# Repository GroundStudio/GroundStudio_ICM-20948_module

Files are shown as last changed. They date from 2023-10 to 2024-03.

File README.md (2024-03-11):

GroundStudio ICM-20948 module
====================================
ICM-20948 module REV0 0 1

Get it from [ardushop.ro](https://ardushop.ro/ro/home/2659-groundstudio-icm-20948.html)

Explore all the GroundStudio products at [GroundStudio.ro](https://groundstudio.ro/)

Description
-------------------
Low power, 9-axis MotionTracking module based on ICM-20948 chip.

Contents
-------------------

* [/Documentation](https://github.com/GroundStudio/GroundStudio_ICM-20948_module/tree/main/Documentation) -- Contains documentation written during creation of this repository, with readme.md index of its own!
* [/Firmware](https://github.com/GroundStudio/GroundStudio_ICM-20948_module/tree/main/Firmware) -- Firmware (bootloaders, etc)
* [/Hardware](https://github.com/GroundStudio/GroundStudio_ICM-20948_module/tree/main/Hardware) -- Schematics, layout.
* [/Libraries](https://github.com/GroundStudio/GroundStudio_ICM-20948_module/tree/main/Libraries) -- Arduino/CircuitPython libraries. 
* [/Tools](https://github.com/GroundStudio/GroundStudio_ICM-20948_module/tree/main) -- Tools needed for compiling, uploading bootloader, etc.

Versions
-------------------
*(Not all tags shown)*
* [V0.0.1] Initial version

License
-------------------

This is released under the [Attribution-ShareAlike 4.0 International (CC BY-SA 4.0)](https://creativecommons.org/licenses/by-sa/4.0/) license. 
**You are welcome to use this for commercial purposes.**

Please consider contributing back to this project or others to help the open-source hardware community continue to thrive and grow! 

Certifications:

[Open Source Hardware Association](https://certification.oshwa.org/ro000015.html)   
   
certification-mark-RO000015-wide (https://certification.oshwa.org/ro000015.html)

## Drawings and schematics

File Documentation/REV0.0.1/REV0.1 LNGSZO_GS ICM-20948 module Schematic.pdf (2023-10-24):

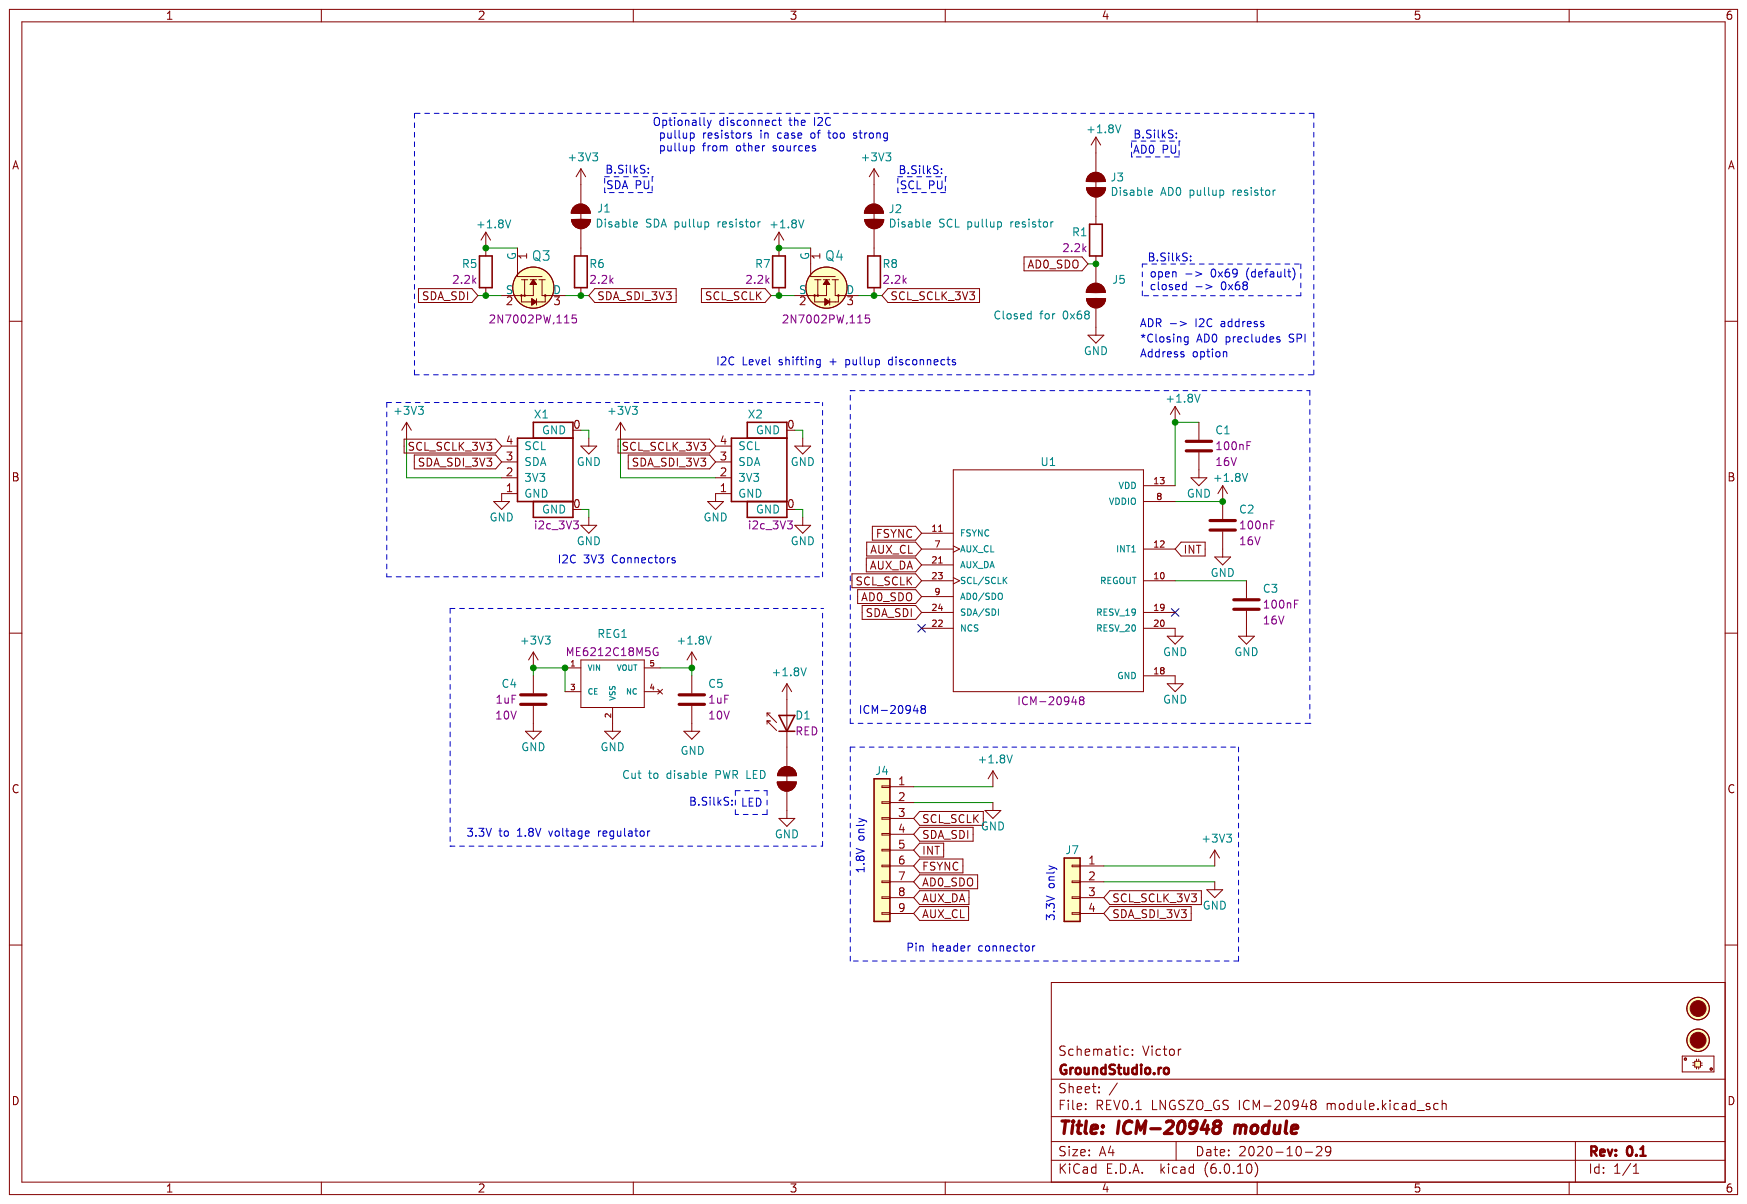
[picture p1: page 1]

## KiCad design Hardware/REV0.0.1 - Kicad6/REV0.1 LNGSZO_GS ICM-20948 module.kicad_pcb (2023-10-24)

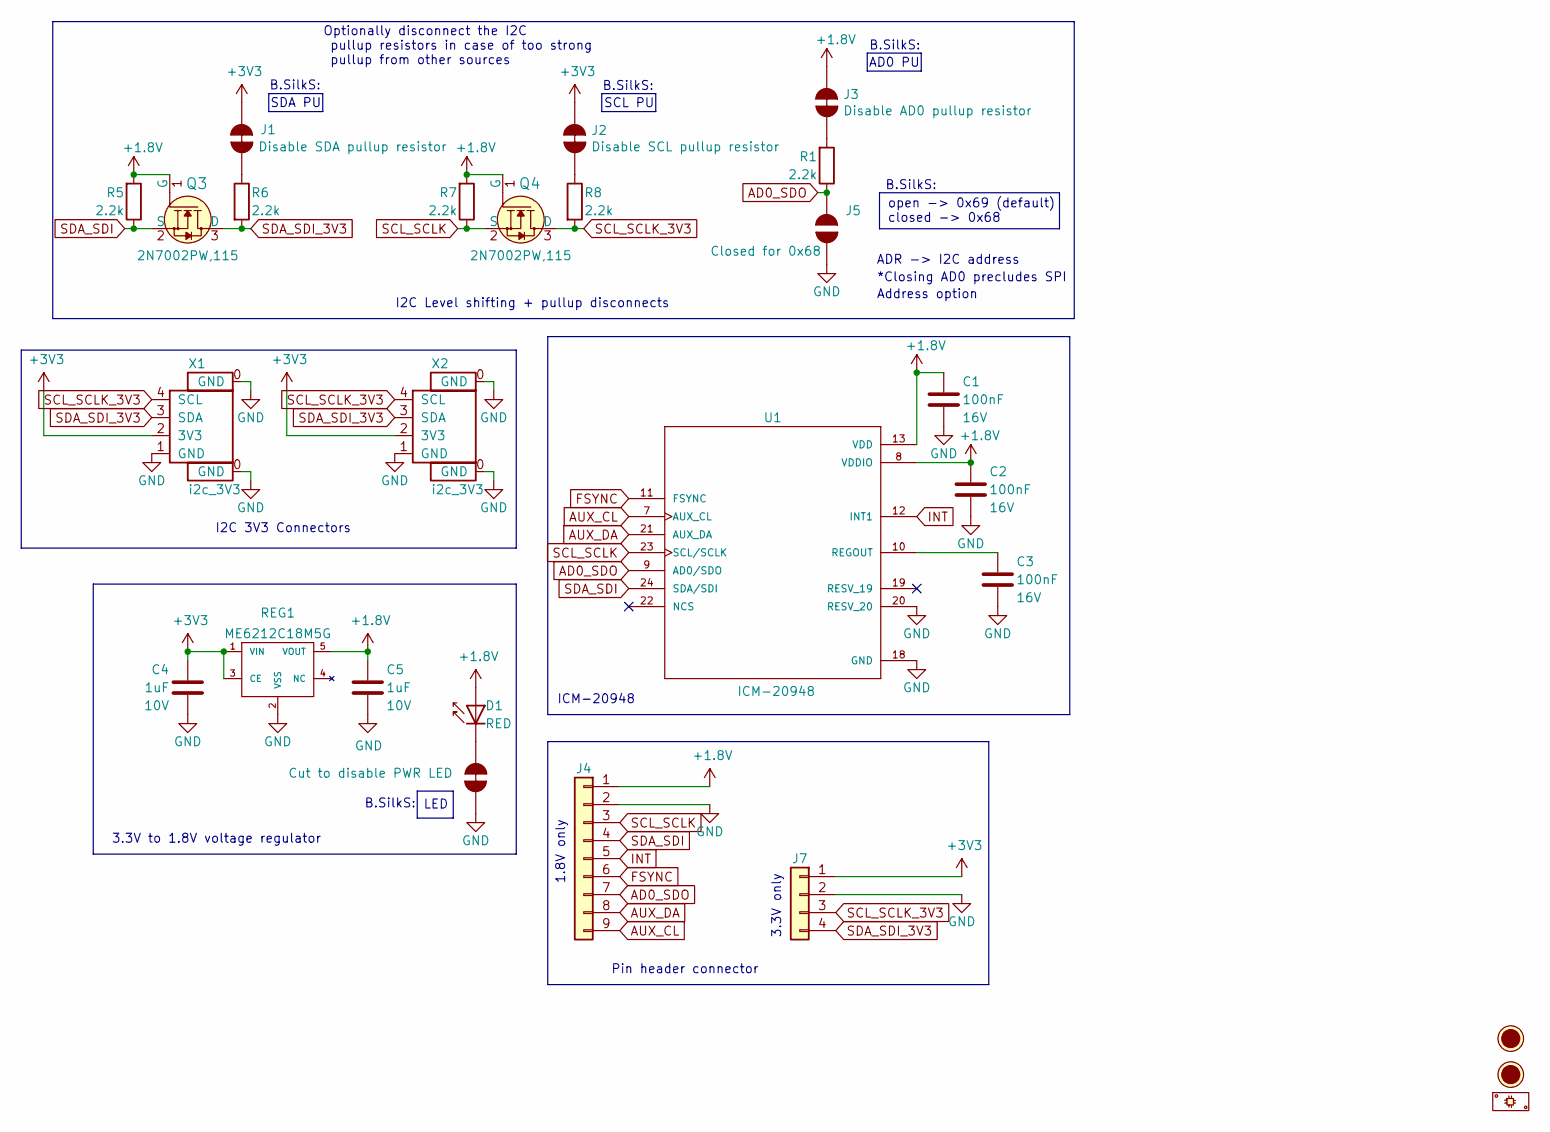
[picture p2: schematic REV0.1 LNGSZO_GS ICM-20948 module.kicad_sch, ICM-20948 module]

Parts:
C1, C2, C3: C_0402_100nF_16V; C_0402; Rated voltage 16V; MPN 0402B104K160CT; LCSC C83056
C4, C5: C_0402_1uF_10V; C_0402; Rated voltage 10V; MPN FS15B105K100PKG; LCSC C525324
D1: LED_0402_RED; LED_0402; MPN TZ-P2-0402RTIA1-0.45T; LCSC C779449
FID1, FID2: Fiducial; Fiducial_0.75mm_Mask1.5mm
J1: Disable SDA pullup resistor; SolderJumper_NC
J2: Disable SCL pullup resistor; SolderJumper_NC
J3: Disable AD0 pullup resistor; SolderJumper_NC
J4: PinHeader_1x09_P2.54_V_M; PinHeader_1x09_P2.54mm_Vertical_Male; MPN A2541WV-9P; LCSC C225484
J5: Closed for 0x68; SolderJumper_NO
J6: Cut to disable PWR LED; SolderJumper_NC
J7: PinHeader_1x04_P2.54_V_M; PinHeader_1x04_P2.54mm_Vertical_Male; MPN MTP125-1104S1; LCSC C358686
P1: PCB; MPN LNGSZO_GS_PCB
Q3, Q4: SOT-323 2N7002PW; SOT-323_SC-70; MPN 2N7002PW,115; LCSC C255579
R1, R5, R6, R7, R8: R_0402_2.2k; R_0402; MPN RC-02W2201FT; LCSC C258093
REG1: SOT-23-5_ME6212C18M5G; SOT-23-5; MPN ME6212C18M5G; LCSC C236669
U1: QFN-24_ICM-20948; QFN-24-0EP_3x3mm_P0.4mm_NO-EP; MPN ICM-20948; Mouser 410-ICM-20948
X1, X2: SH_1x04_P1.0_H; SH__1x04_P1.00mm_Horizontal; MPN C145956; LCSC C145956

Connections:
+1.8V: C1.1, C2.1, C5.1, D1.2 (A), J3.1, J4.1, Q3.1 (G), Q4.1 (G), R5.2, R7.2, REG1.5 (VOUT), U1.8 (VDDIO), U1.13 (VDD)
+3V3: C4.2, J1.1, J2.1, J7.1, REG1.1 (VIN), REG1.3 (CE), X1.2 (3V3), X2.2 (3V3)
AD0_SDO: J4.7, J5.1, R1.1, U1.9 (AD0/SDO)
AUX_CL: J4.9, U1.7 (AUX_CL)
AUX_DA: J4.8, U1.21 (AUX_DA)
FSYNC: J4.6, U1.11 (FSYNC)
GND: C1.2, C2.2, C3.2, C4.1, C5.2, J4.2, J5.2, J6.1, J7.2, REG1.2 (VSS), U1.18 (GND), U1.20 (RESV_20), X1.0 (GND), X1.1 (GND), X2.0 (GND), X2.1 (GND)
INT: J4.5, U1.12 (INT1)
unnamed: C3.1, U1.10 (REGOUT)
unnamed: D1.1 (K), J6.2
unnamed: J1.2, R6.1
unnamed: J2.2, R8.1
unnamed: J3.2, R1.2
SCL_SCLK: J4.3, Q4.2 (S), R7.1, U1.23 (SCL/SCLK)
SCL_SCLK_3V3: J7.3, Q4.3 (D), R8.2, X1.4 (SCL), X2.4 (SCL)
SDA_SDI: J4.4, Q3.2 (S), R5.1, U1.24 (SDA/SDI)
SDA_SDI_3V3: J7.4, Q3.3 (D), R6.2, X1.3 (SDA), X2.3 (SDA)

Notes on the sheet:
LED
I2C 3V3 Connectors
3.3V only
B.SilkS:
Address option
AD0 PU
SDA PU
SCL PU
open -> 0x69 (default) closed -> 0x68
Optionally disconnect the I2C pullup resistors in case of too strong pullup from other sources
3.3V to 1.8V voltage regulator
*Closing AD0 precludes SPI
ADR -> I2C address
ICM-20948
I2C Level shifting + pullup disconnects
Pin header connector
1.8V only

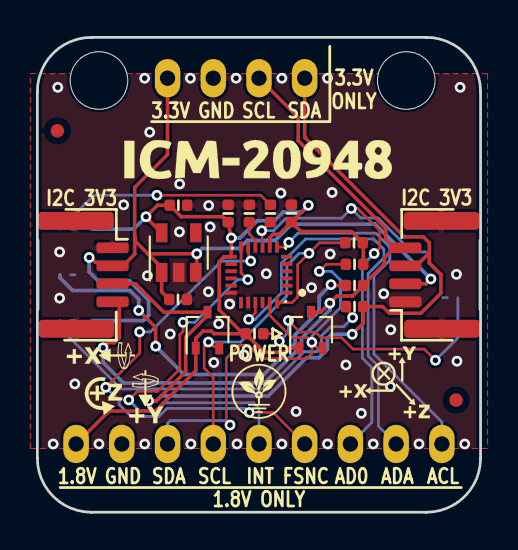
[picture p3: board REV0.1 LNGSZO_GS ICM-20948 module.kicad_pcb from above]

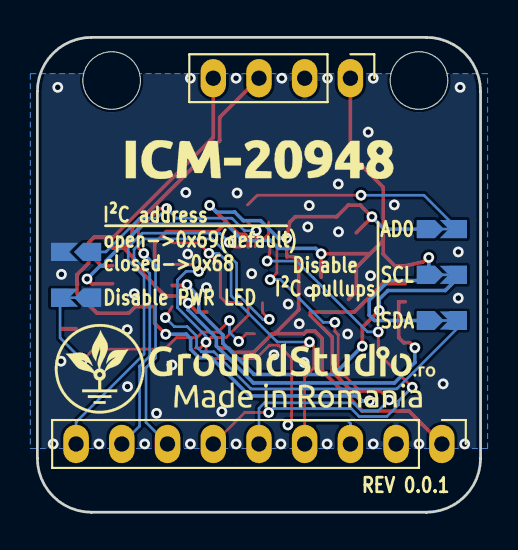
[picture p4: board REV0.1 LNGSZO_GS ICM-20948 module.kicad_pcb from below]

Board: 2 copper layers, 24.6 x 26.4 mm, 26 parts (7 on the bottom side), 17 nets.
